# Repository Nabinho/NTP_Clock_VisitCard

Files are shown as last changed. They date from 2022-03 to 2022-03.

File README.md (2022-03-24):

# NTP_Clock_VisitCard

Linkit 7697 based NTP Digital Clock with a Visti Card PCB

I have the idea of creating an Visit Card to promote myself as a Software and Hardware Developer and project consultant, and for that I decided to go with a PCB in the format of a Credit Card. The circuit chosen is a project I always wanted to build, as I don´t have clocks due to the time to time need for manual calibration. So I connected the LinkIt 7697 (unfortunately discontinued) I had available, to connect it to a NTP server, and be always up to time. The board then controls 4 7-digits displays by 4 4511 ICs that are indirectly driven by ULN2003 transistors.

If you are interested in building your own Visit Card based on this project, feel free to change the PCB file with your own information. Just remember to give some credit.

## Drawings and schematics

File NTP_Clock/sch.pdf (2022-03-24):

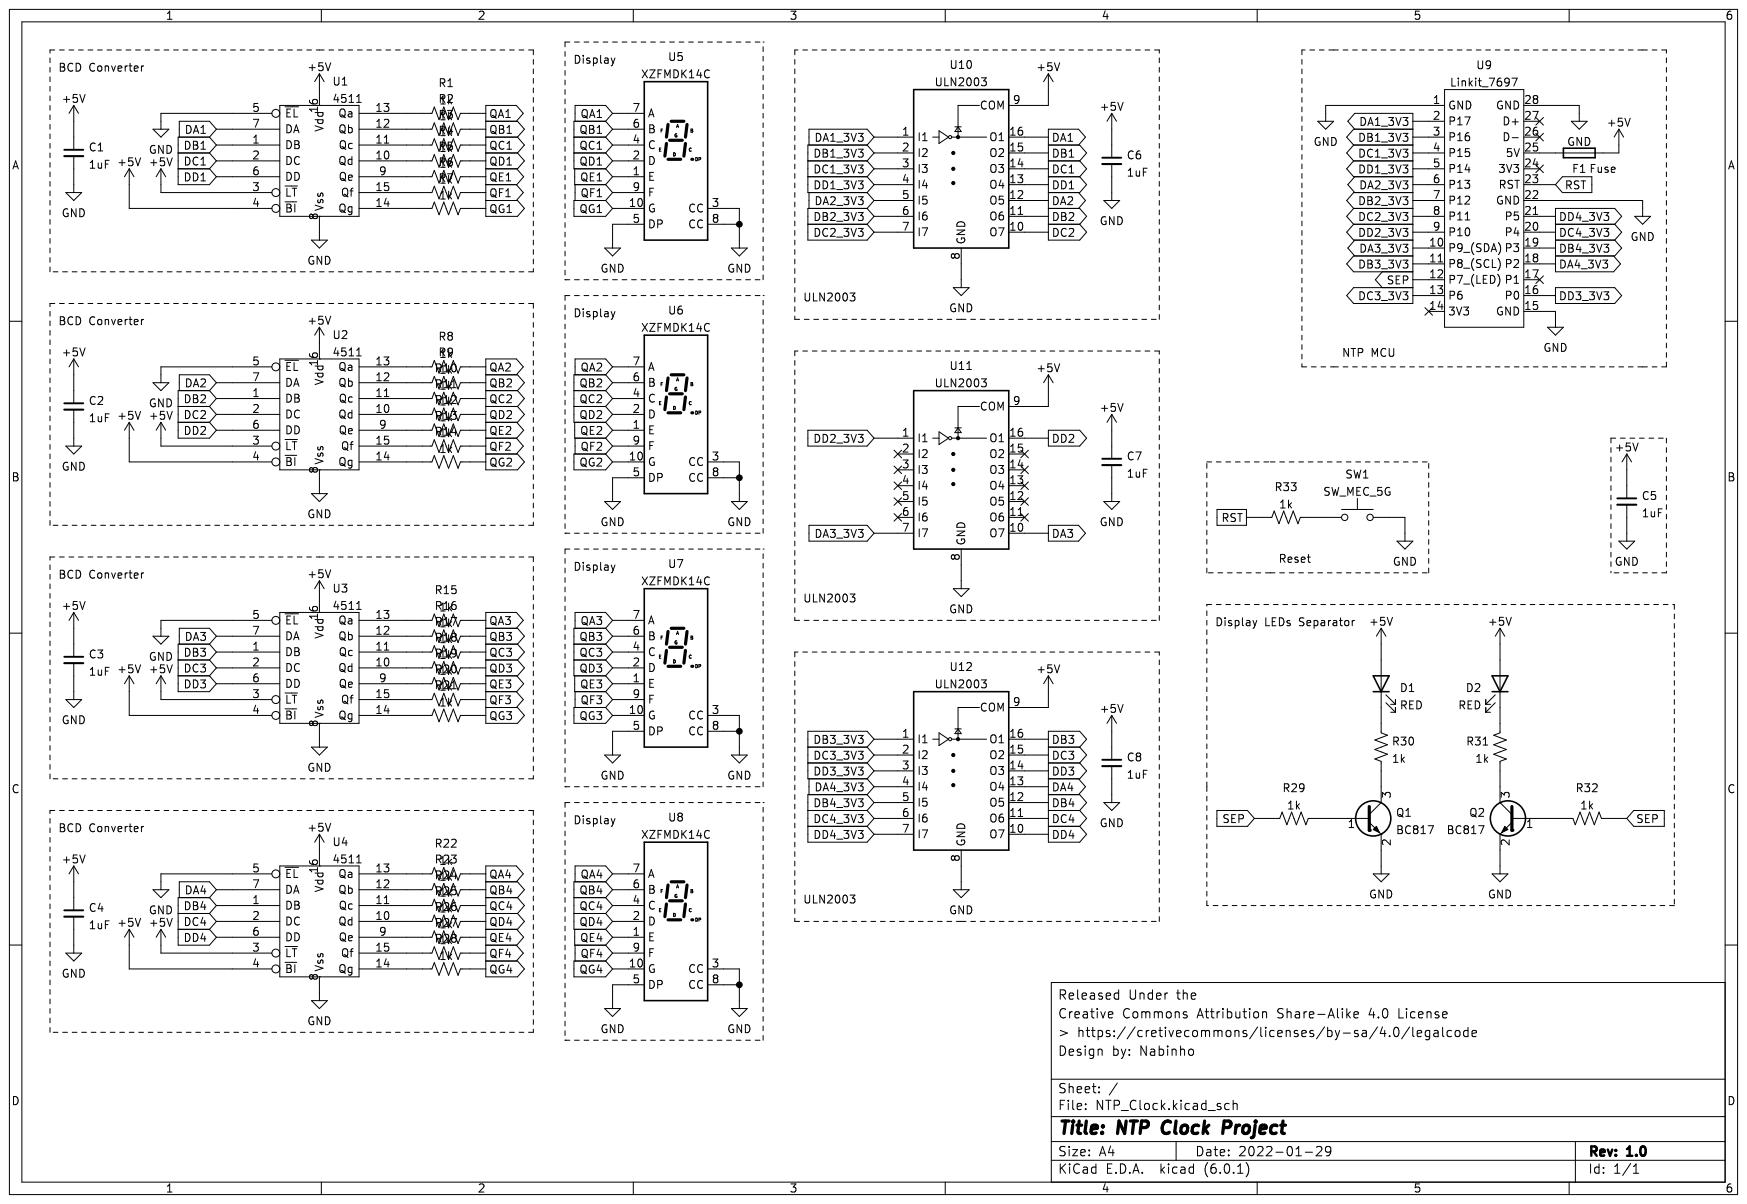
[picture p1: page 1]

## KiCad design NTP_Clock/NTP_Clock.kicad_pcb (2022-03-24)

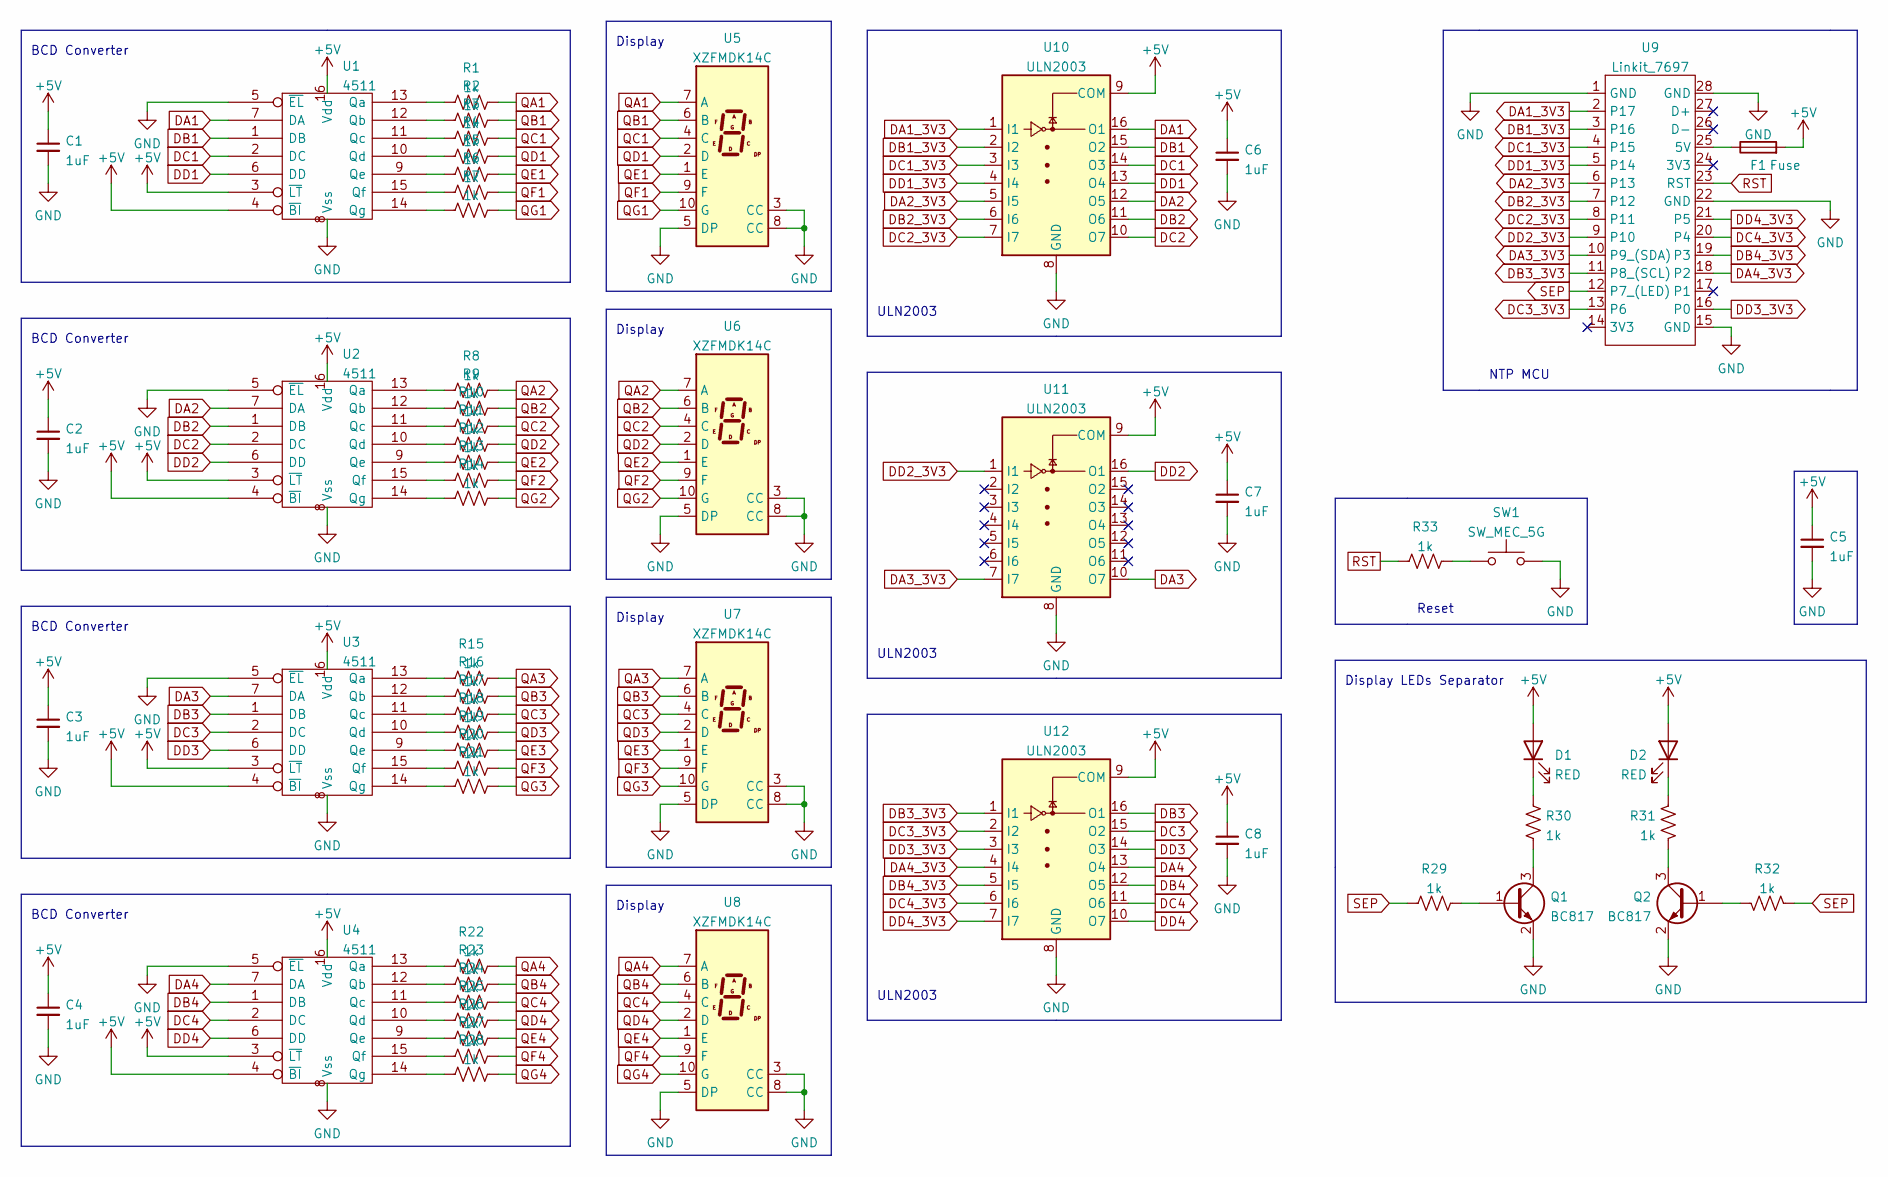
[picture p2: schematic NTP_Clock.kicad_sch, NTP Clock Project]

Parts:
C1, C2, C3, C4, C5, C6, C7, C8: 1uF; C_0805_2012Metric
D1, D2: RED; LED_0805_2012Metric
F1: Fuse; Fuse_0805_2012Metric
Q1, Q2: BC817; SOT-23
R1, R2, R3, R4, R5, R6, R7, R8, R9, R10, R11, R12, R13, R14, R15, R16, R17, R18, R19, R20, R21, R22, R23, R24, R25, R26, R27, R28, R29, R30, R31, R32, R33: 1k; R_0805_2012Metric
SW1: SW_MEC_5G; SW_SPST_SKQG_WithStem
U1, U2, U3, U4: 4511; SO-16_5.3x10.2mm_P1.27mm
U5, U6, U7, U8: XZFMDK14C; 7SEGMENT-LED__HDSM531_HDSM533_SMD
U9: Linkit_7697; Linkit
U10, U11, U12: ULN2003; SO-16_5.3x10.2mm_P1.27mm

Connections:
+5V: C1.1, C2.1, C3.1, C4.1, C5.1, C6.1, C7.1, C8.1, D1.2 (A), D2.2 (A), F1.2, U1.3 (~LT), U1.4 (~BI), U1.16 (Vdd), U2.3 (~LT), U2.4 (~BI), U2.16 (Vdd), U3.3 (~LT), U3.4 (~BI), U3.16 (Vdd), U4.3 (~LT), U4.4 (~BI), U4.16 (Vdd), U10.9 (COM), U11.9 (COM), U12.9 (COM)
DA1: U1.7 (DA), U10.16 (O1)
DA1_3V3: U9.2 (P17), U10.1 (I1)
DA2: U2.7 (DA), U10.12 (O5)
DA2_3V3: U9.6 (P13), U10.5 (I5)
DA3: U3.7 (DA), U11.10 (O7)
DA3_3V3: U9.10 (P9_(SDA)), U11.7 (I7)
DA4: U4.7 (DA), U12.13 (O4)
DA4_3V3: U9.18 (P2), U12.4 (I4)
DB1: U1.1 (DB), U10.15 (O2)
DB1_3V3: U9.3 (P16), U10.2 (I2)
DB2: U2.1 (DB), U10.11 (O6)
DB2_3V3: U9.7 (P12), U10.6 (I6)
DB3: U3.1 (DB), U12.16 (O1)
DB3_3V3: U9.11 (P8_(SCL)), U12.1 (I1)
DB4: U4.1 (DB), U12.12 (O5)
DB4_3V3: U9.19 (P3), U12.5 (I5)
DC1: U1.2 (DC), U10.14 (O3)
DC1_3V3: U9.4 (P15), U10.3 (I3)
DC2: U2.2 (DC), U10.10 (O7)
DC2_3V3: U9.8 (P11), U10.7 (I7)
DC3: U3.2 (DC), U12.15 (O2)
DC3_3V3: U9.13 (P6), U12.2 (I2)
DC4: U4.2 (DC), U12.11 (O6)
DC4_3V3: U9.20 (P4), U12.6 (I6)
DD1: U1.6 (DD), U10.13 (O4)
DD1_3V3: U9.5 (P14), U10.4 (I4)
DD2: U2.6 (DD), U11.16 (O1)
DD2_3V3: U9.9 (P10), U11.1 (I1)
DD3: U3.6 (DD), U12.14 (O3)
DD3_3V3: U9.16 (P0), U12.3 (I3)
DD4: U4.6 (DD), U12.10 (O7)
DD4_3V3: U9.21 (P5), U12.7 (I7)
unnamed: D1.1 (K), R30.2
unnamed: D2.1 (K), R31.2
unnamed: F1.1, U9.25 (5V)
unnamed: Q1.1 (B), R29.2
unnamed: Q1.3 (C), R30.1
unnamed: Q2.1 (B), R32.2
unnamed: Q2.3 (C), R31.1
unnamed: R1.1, U1.13 (Qa)
unnamed: R2.1, U1.12 (Qb)
unnamed: R3.1, U1.11 (Qc)
unnamed: R4.1, U1.10 (Qd)
unnamed: R5.1, U1.9 (Qe)
unnamed: R6.1, U1.15 (Qf)
unnamed: R7.1, U1.14 (Qg)
unnamed: R8.1, U2.13 (Qa)
unnamed: R9.1, U2.12 (Qb)
unnamed: R10.1, U2.11 (Qc)
unnamed: R11.1, U2.10 (Qd)
unnamed: R12.1, U2.9 (Qe)
unnamed: R13.1, U2.15 (Qf)
unnamed: R14.1, U2.14 (Qg)
unnamed: R15.1, U3.13 (Qa)
unnamed: R16.1, U3.12 (Qb)
unnamed: R17.1, U3.11 (Qc)
unnamed: R18.1, U3.10 (Qd)
unnamed: R19.1, U3.9 (Qe)
unnamed: R20.1, U3.15 (Qf)
unnamed: R21.1, U3.14 (Qg)
unnamed: R22.1, U4.13 (Qa)
unnamed: R23.1, U4.12 (Qb)
unnamed: R24.1, U4.11 (Qc)
unnamed: R25.1, U4.10 (Qd)
unnamed: R26.1, U4.9 (Qe)
unnamed: R27.1, U4.15 (Qf)
unnamed: R28.1, U4.14 (Qg)
QA1: R1.2, U5.7 (A)
QA2: R8.2, U6.7 (A)
QA3: R15.2, U7.7 (A)
QA4: R22.2, U8.7 (A)
QB1: R2.2, U5.6 (B)
QB2: R9.2, U6.6 (B)
QB3: R16.2, U7.6 (B)
QB4: R23.2, U8.6 (B)
QC1: R3.2, U5.4 (C)
QC2: R10.2, U6.4 (C)
QC3: R17.2, U7.4 (C)
QC4: R24.2, U8.4 (C)
QD1: R4.2, U5.2 (D)
QD2: R11.2, U6.2 (D)
QD3: R18.2, U7.2 (D)
QD4: R25.2, U8.2 (D)
QE1: R5.2, U5.1 (E)
QE2: R12.2, U6.1 (E)
QE3: R19.2, U7.1 (E)
QE4: R26.2, U8.1 (E)
QF1: R6.2, U5.9 (F)
QF2: R13.2, U6.9 (F)
QF3: R20.2, U7.9 (F)
QF4: R27.2, U8.9 (F)
QG1: R7.2, U5.10 (G)
QG2: R14.2, U6.10 (G)
QG3: R21.2, U7.10 (G)
QG4: R28.2, U8.10 (G)
RST: R33.1, U9.23 (RST)
SEP: R29.1, R32.1, U9.12 (P7_(LED))

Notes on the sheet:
ULN2003
Display
Reset
BCD Converter
NTP MCU
Display LEDs Separator

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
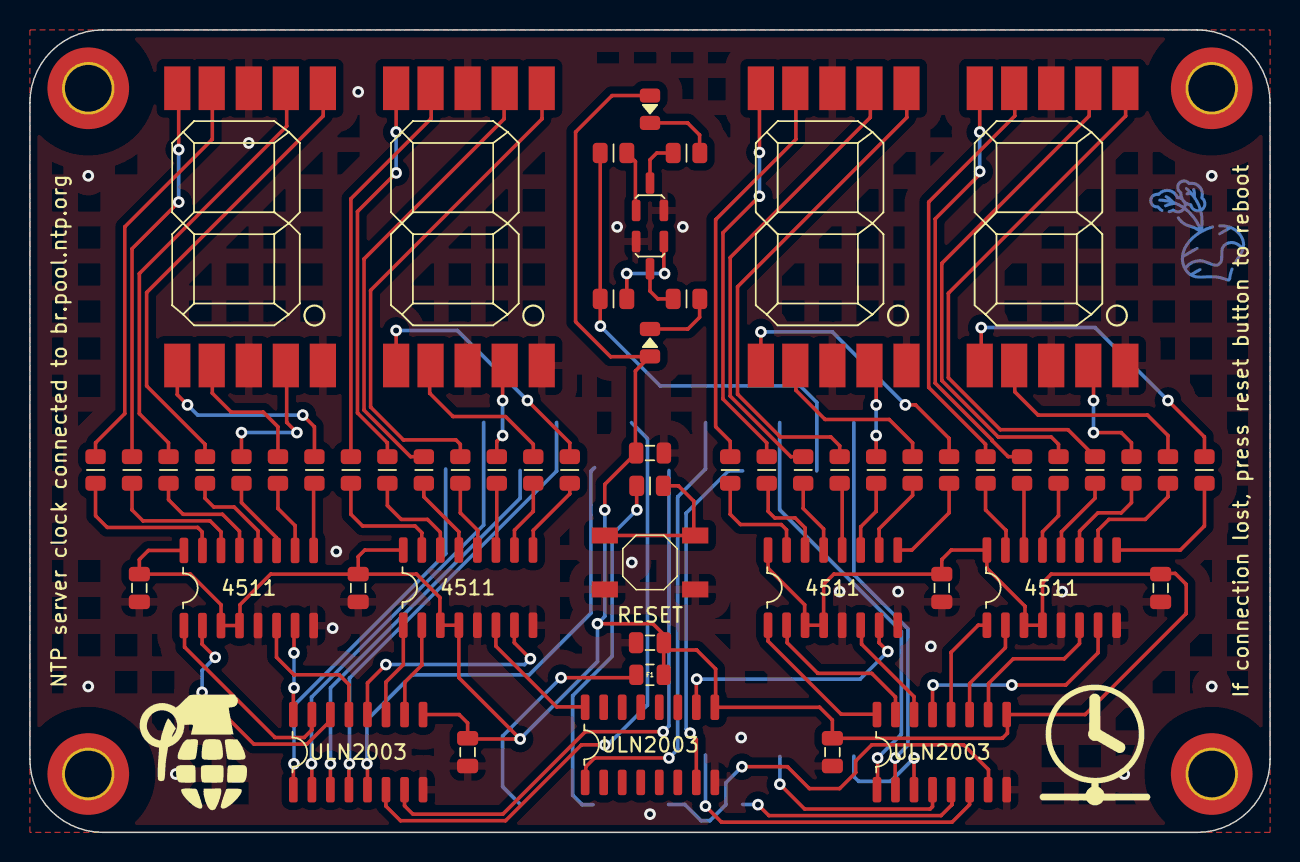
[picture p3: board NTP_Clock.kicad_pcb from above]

Board: 2 copper layers, 85.0 x 55.0 mm, 59 parts (1 on the bottom side), 100 nets.

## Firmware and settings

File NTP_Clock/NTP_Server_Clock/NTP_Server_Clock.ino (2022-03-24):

//Board Selection Verification
#if !defined(ARDUINO_linkit_7697) //Linkit 7697
#error Use this code with Linkit 7697
#endif

//DEBUG habilitation
//Comment if unecessary DEBUG
#define DEBUG

//Libraries
#include <NTPClient.h>
#include <LWiFi.h>
#include <WiFiUdp.h>

//PCB Control PINS
//#define LED_BUILTIN 7
#define DA1 17
#define DB1 16
#define DC1 15
#define DD1 14
#define DA2 13
#define DB2 12
#define DC2 11
#define DD2 10
#define DA3 9
#define DB3 8
#define DC3 6
#define DD3 0
#define DA4 2
#define DB4 3
#define DC4 4
#define DD4 5

//Control Arrays
const int BCD_N = 4;
const int BCD_arrayN = 4;
const int BCD_Controls[BCD_N][BCD_arrayN] =
{ {DA1, DB1, DC1, DD1},
  {DA2, DB2, DC2, DD2},
  {DA3, DB3, DC3, DD3},
  {DA4, DB4, DC4, DD4}
};

//Wi-Fi parameters
char ssid[] = "Castro_2g";      //  your network SSID (name)
char pass[] = "pau4ka@@";   // your network password

//NTP UDP object
WiFiUDP ntpUDP;

// You can specify the time server pool and the offset, (in seconds)
// additionally you can specify the update interval (in milliseconds).
NTPClient timeClient(ntpUDP, "br.pool.ntp.org", -10800);

//Wi-Fi connection status
int status = WL_IDLE_STATUS;

//System variables
String tempo = "";
String horas = "";
String minutos = "";
String segundos = "";
int horai = 0;
int minutoi = 0;
int segundoi = 0;
int horai1 = 0;
int horai2 = 0;
int minutoi1 = 0;
int minutoi2 = 0;
int segundoi1 = 0;
int segundoi2 = 0;

//Time control variables
unsigned long tempo_antes = 0;
const int SEGUNDO = 1000;

void setup() {

  //Initialization
#ifdef DEBUG
  Serial.begin(9600);
  Serial.println("--* Linkit 7697 NTP Server Clock *--");
#endif
  delay(1000);

  //Connection
  while ( status != WL_CONNECTED ) {
    Serial.print("Conectando a rede: ");
    Serial.print(ssid);
    Serial.print( "." );
    status = WiFi.begin(ssid, pass);
  }

  //NTP server initialization
  timeClient.begin();
#ifdef DEBUG
  Serial.println("");
  printWifiStatus();
  Serial.println("Conectado e sistema iniciado\n\n");
#endif

  //User LED initialization
  //pinMode(LED_BUILTIN, OUTPUT);
  //digitalWrite(LED_BUILTIN, LOW);

  //BCD Controls Configuration Startup
  for (int j = 0; j < BCD_N; j++) {
    for (int i = 0; i < BCD_arrayN; i++) {
      pinMode(BCD_Controls[j][i], OUTPUT);
      digitalWrite(BCD_Controls[j][i], !0);
    }
  }



}

void loop() {

  //Every 1 minute reads server time
  if ((millis() - tempo_antes) > SEGUNDO) {

    //Update NTP time
    timeClient.update();
    tempo = timeClient.getFormattedTime();
    digitalWrite(LED_BUILTIN, !digitalRead(LED_BUILTIN));

#ifdef DEBUG
    Serial.print(tempo);
    Serial.println (" - original string");
#endif

    //Separates values from server return
    horas = getValue(tempo, ':', 0);
    minutos = getValue(tempo, ':', 1);
    segundos = getValue (tempo, ':', 2);

#ifdef DEBUG
    Serial.print(horas);
    Serial.print(":");
    Serial.print(minutos);
    Serial.print(":");
    Serial.print(segundos);
    Serial.println(" - string separado");
#endif

    //Converts String to Int
    horai = horas.toInt();
    minutoi = minutos.toInt();
    segundoi = segundos.toInt();

#ifdef DEBUG
    if (horai < 10) {
      Serial.print("0");
      Serial.print(horai);
    } else {
      Serial.print(horai);
    }
    Serial.print(":");
    if (minutoi < 10) {
      Serial.print("0");
      Serial.print(minutoi);
    } else {
      Serial.print(minutoi);
    }
    Serial.print(":");
    if (segundoi < 10) {
      Serial.print("0");
      Serial.print(segundoi);
    } else {
      Serial.print(segundoi);
    }
    Serial.println(" - inteiro convertido");
#endif

    //Separates Int values
    if (horai >= 10) {
      horai1 = (horai / 10) % 10;
      horai2 = horai % 10;
    } else {
      horai1 = 0;
      horai2 = horai;
    }

    if (minutoi >= 10) {
      minutoi1 = (minutoi / 10) % 10;
      minutoi2 = minutoi % 10;
    } else {
      minutoi1 = 0;
      minutoi2 = minutoi;
    }

    if (segundoi >= 10) {
      segundoi1 = (segundoi / 10) % 10;
      segundoi2 = segundoi % 10;
    } else {
      segundoi1 = 0;
      segundoi2 = segundoi;
    }

#ifdef DEBUG
    Serial.print(horai1);
    Serial.print(horai2);
    Serial.print(":");
    Serial.print(minutoi1);
    Serial.print(minutoi2);
    Serial.print(":");
    Serial.print(segundoi1);
    Serial.print(segundoi2);
    Serial.println(" - inteiro separado");
#endif

    //Control Displays by BCDs Converters
    ControlBCD(horai1, 0);
    ControlBCD(horai2, 1);
    ControlBCD(minutoi1, 2);
    ControlBCD(minutoi2, 3);

    #ifdef DEBUG
    Serial.println("\n");
    #endif

    //Updates time counter for loop
    tempo_antes = millis();

  }
}

//Funtion to separate the server response
String getValue(String data, char separator, int index) {

  int found = 0;
  int strIndex[] = { 0, -1 };
  int maxIndex = data.length() - 1;

  for (int i = 0; i <= maxIndex && found <= index; i++) {
    if (data.charAt(i) == separator || i == maxIndex) {
      found++;
      strIndex[0] = strIndex[1] + 1;
      strIndex[1] = (i == maxIndex) ? i + 1 : i;
    }
  }

  return found > index ? data.substring(strIndex[0], strIndex[1]) : "";

}

//Wi-Fi return
void printWifiStatus() {

  //Print your WiFi shield's IP address:
  IPAddress ip = WiFi.localIP();
  Serial.print("Endereco de IP: ");
  Serial.println(ip);

  //Print the received signal strength:
  Serial.print("Forca da conexao (RSSI): ");
  Serial.print(WiFi.RSSI());
  Serial.println(" dBm");

}

//Function to set BCD Converter input pins logic level
void ControlBCD(int digit, int BCD) {
#ifdef DEBUG
  Serial.print("Requisitado digito: ");
  Serial.print(digit);
  Serial.print(" para o BCD");
  Serial.println(BCD + 1);
#endif
  switch (digit) {
    case 0:
    #ifdef DEBUG
    Serial.println("Case0");
    #endif
      digitalWrite(BCD_Controls[BCD][0], !0);
      digitalWrite(BCD_Controls[BCD][1], !0);
      digitalWrite(BCD_Controls[BCD][2], !0);
      digitalWrite(BCD_Controls[BCD][3], !0);
      break;
    case 1:
    #ifdef DEBUG
    Serial.println("Case1");
    #endif
      digitalWrite(BCD_Controls[BCD][0], !1);
      digitalWrite(BCD_Controls[BCD][1], !0);
      digitalWrite(BCD_Controls[BCD][2], !0);
      digitalWrite(BCD_Controls[BCD][3], !0);
      break;
    case 2:
    #ifdef DEBUG
    Serial.println("Case2");
    #endif
      digitalWrite(BCD_Controls[BCD][0], !0);
      digitalWrite(BCD_Controls[BCD][1], !1);
      digitalWrite(BCD_Controls[BCD][2], !0);
      digitalWrite(BCD_Controls[BCD][3], !0);
      break;
    case 3:
    #ifdef DEBUG
    Serial.println("Case3");
    #endif
      digitalWrite(BCD_Controls[BCD][0], !1);
      digitalWrite(BCD_Controls[BCD][1], !1);
      digitalWrite(BCD_Controls[BCD][2], !0);
      digitalWrite(BCD_Controls[BCD][3], !0);
      break;
    case 4:
    #ifdef DEBUG
    Serial.println("Case4");
    #endif
      digitalWrite(BCD_Controls[BCD][0], !0);
      digitalWrite(BCD_Controls[BCD][1], !0);
      digitalWrite(BCD_Controls[BCD][2], !1);
      digitalWrite(BCD_Controls[BCD][3], !0);
      break;
    case 5:
    #ifdef DEBUG
    Serial.println("Case5");
    #endif
      digitalWrite(BCD_Controls[BCD][0], !1);
      digitalWrite(BCD_Controls[BCD][1], !0);
      digitalWrite(BCD_Controls[BCD][2], !1);
      digitalWrite(BCD_Controls[BCD][3], !0);
      break;
    case 6:
    #ifdef DEBUG
    Serial.println("Case6");
    #endif
      digitalWrite(BCD_Controls[BCD][0], !0);
      digitalWrite(BCD_Controls[BCD][1], !1);
      digitalWrite(BCD_Controls[BCD][2], !1);
      digitalWrite(BCD_Controls[BCD][3], !0);
      break;
    case 7:
    #ifdef DEBUG
    Serial.println("Case7");
    #endif
      digitalWrite(BCD_Controls[BCD][0], !1);
      digitalWrite(BCD_Controls[BCD][1], !1);
      digitalWrite(BCD_Controls[BCD][2], !1);
      digitalWrite(BCD_Controls[BCD][3], !0);
      break;
    case 8:
    #ifdef DEBUG
    Serial.println("Case8");
    #endif
      digitalWrite(BCD_Controls[BCD][0], !0);
      digitalWrite(BCD_Controls[BCD][1], !0);
      digitalWrite(BCD_Controls[BCD][2], !0);
      digitalWrite(BCD_Controls[BCD][3], !1);
      break;
    case 9:
    #ifdef DEBUG
    Serial.println("Case9");
    #endif
      digitalWrite(BCD_Controls[BCD][0], !1);
      digitalWrite(BCD_Controls[BCD][1], !0);
      digitalWrite(BCD_Controls[BCD][2], !0);
      digitalWrite(BCD_Controls[BCD][3], !1);
      break;
  }
}

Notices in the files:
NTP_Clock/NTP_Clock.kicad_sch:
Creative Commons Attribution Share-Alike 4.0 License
